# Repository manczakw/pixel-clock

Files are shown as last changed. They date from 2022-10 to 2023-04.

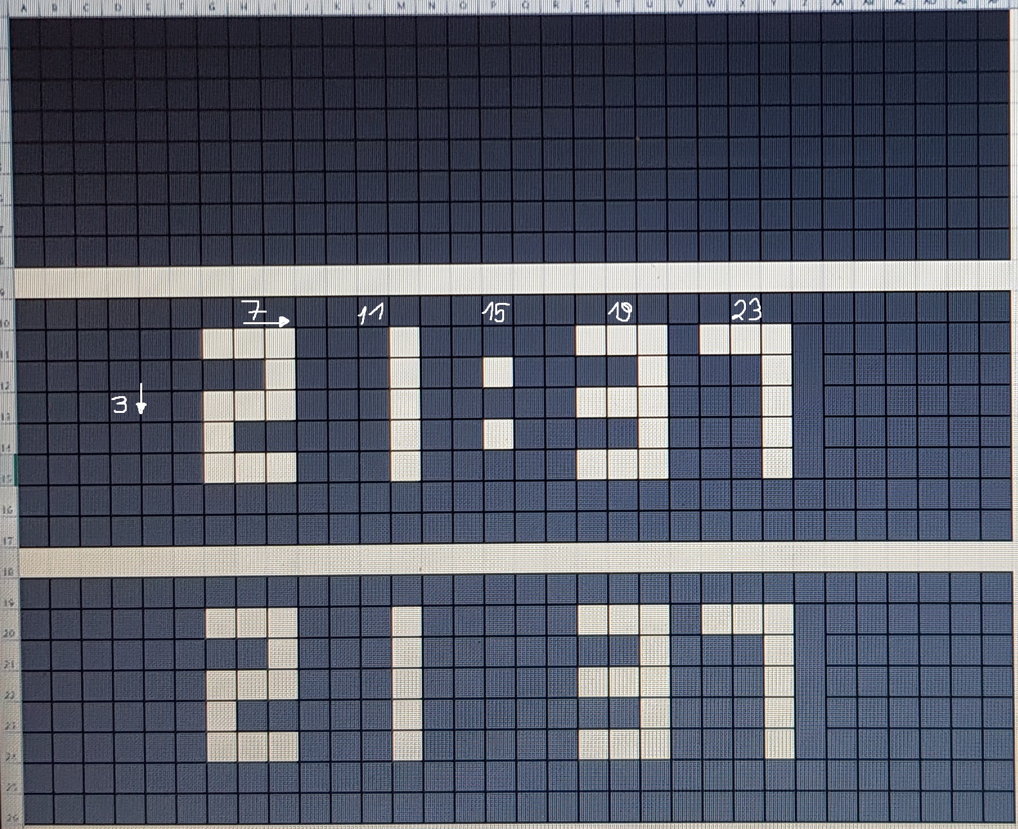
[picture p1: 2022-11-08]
Software/Time positioning.jpg

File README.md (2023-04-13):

Smart LED Pixel Clock
https://www.thingiverse.com/thing:5729760

Vievports

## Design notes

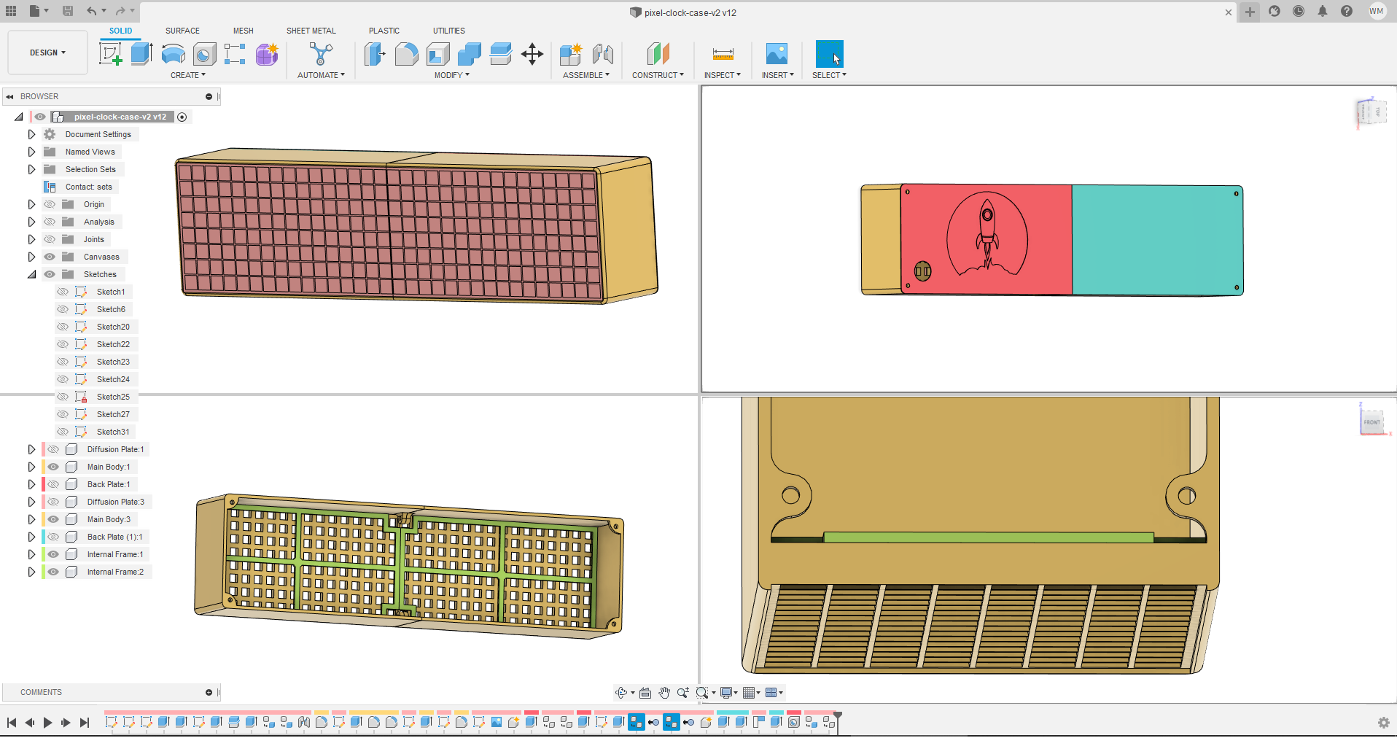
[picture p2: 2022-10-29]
Hardware/Case/CaseV2.0/Vievports.png

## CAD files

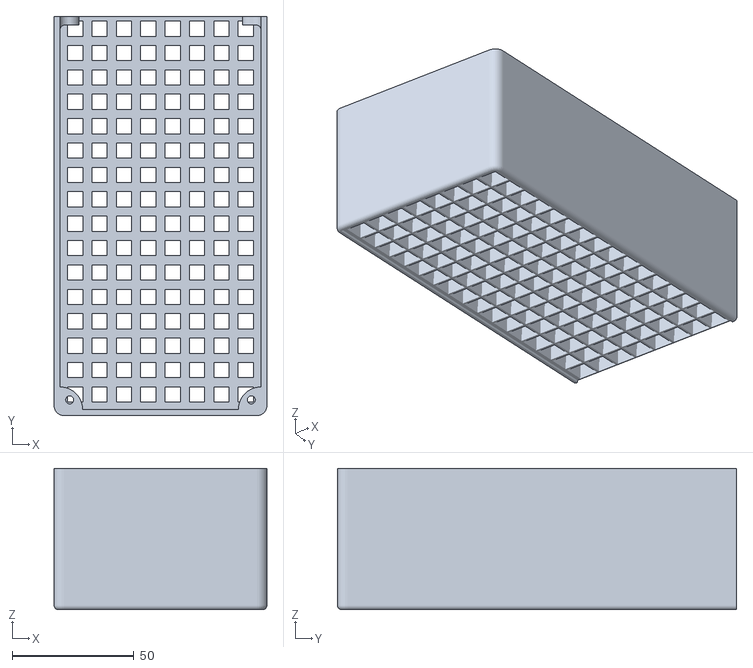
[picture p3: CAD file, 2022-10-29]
Hardware/Case/CaseV2.0/Main Body.stl
87.3 x 163.6 x 58.0

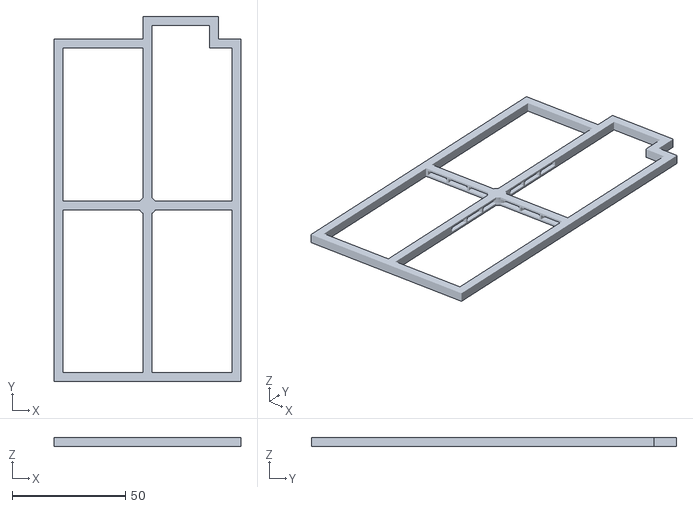
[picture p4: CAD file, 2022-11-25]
Hardware/Case/CaseV2.0/Internal Frame.stl
82.5 x 161.2 x 4.00

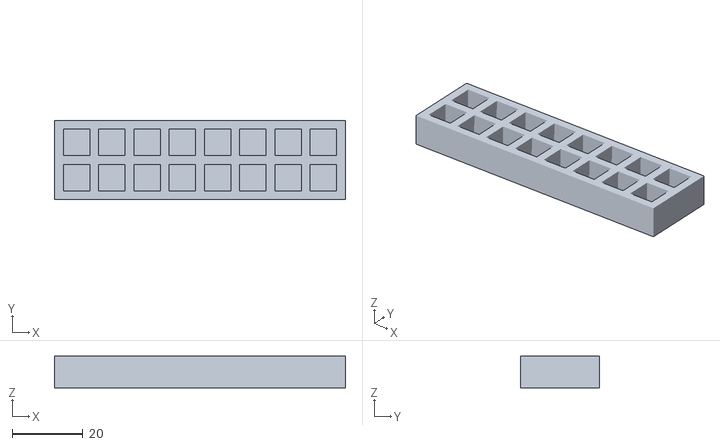
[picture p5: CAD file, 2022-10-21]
Hardware/Case/Layer Thickness test/0_12mm test 2x8.stl
82.5 x 22.5 x 9.01

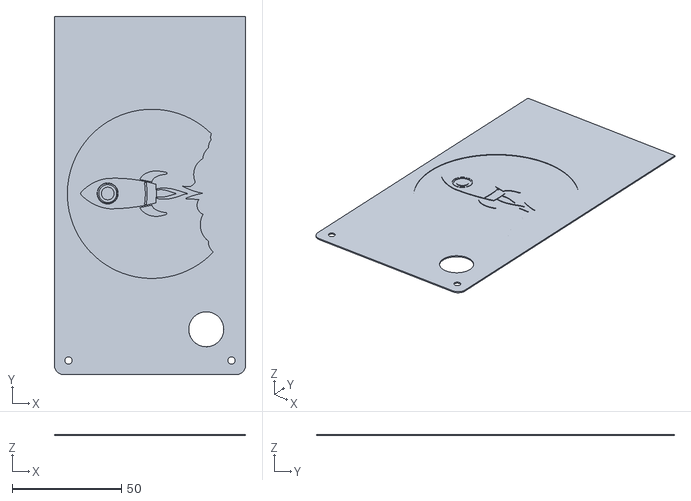
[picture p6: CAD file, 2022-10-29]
Hardware/Case/CaseV2.0/Back Plate ROCKET.stl
87.3 x 163.6 x 0.6

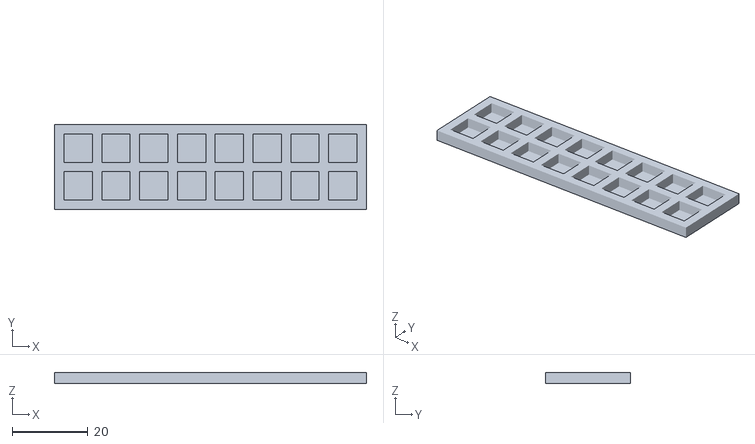
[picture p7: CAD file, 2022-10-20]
Hardware/Case/Layer Thickness test/0_2mm test 2x8.stl
82.5 x 22.5 x 2.95

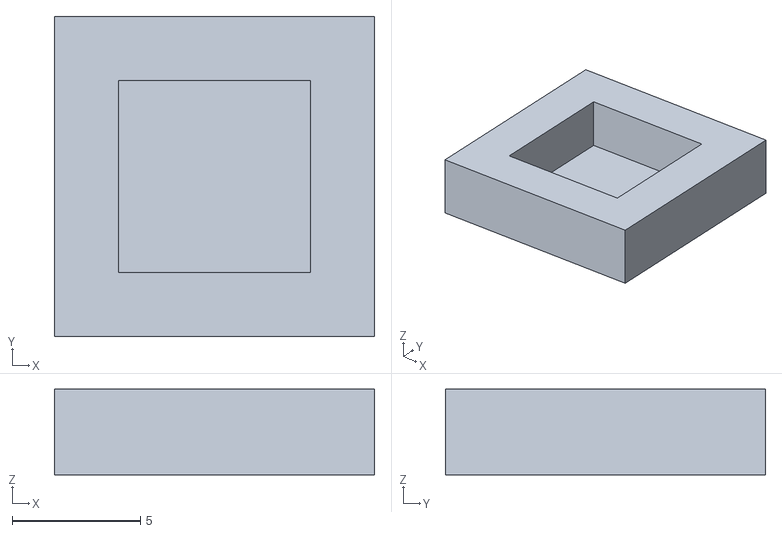
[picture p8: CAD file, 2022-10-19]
Hardware/Case/Layer Thickness test/0_6mm test.stl
12.5 x 12.5 x 3.35

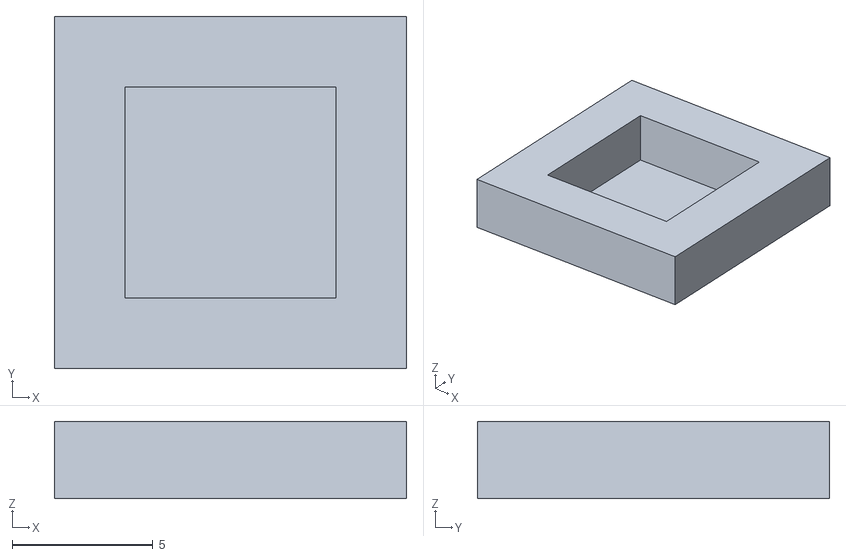
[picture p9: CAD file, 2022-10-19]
Hardware/Case/Layer Thickness test/0_2mm test.stl
12.5 x 12.5 x 2.75

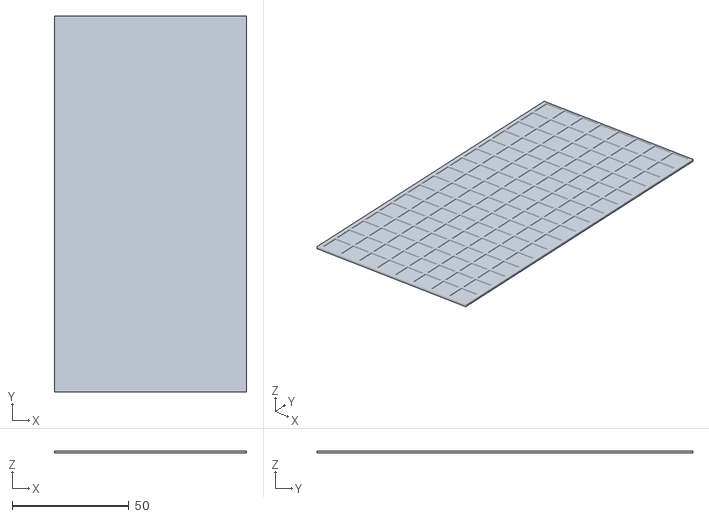
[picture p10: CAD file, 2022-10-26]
Hardware/Case/CaseV2.0/Diffusion Plate.stl
82.5 x 161.2 x 1.02

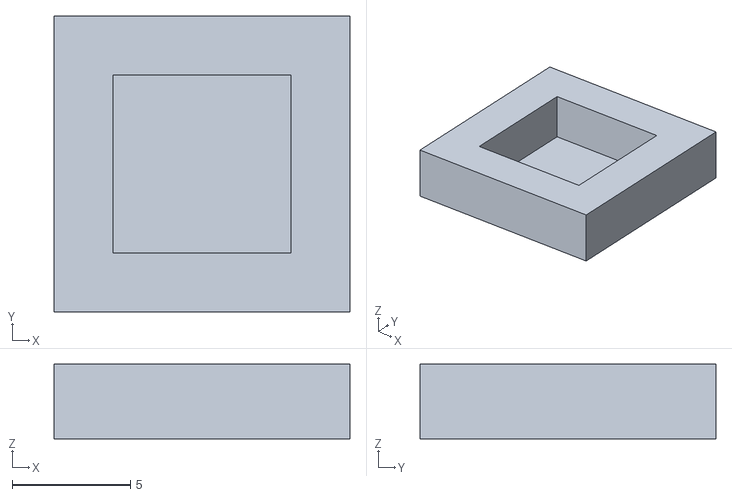
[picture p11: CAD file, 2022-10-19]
Hardware/Case/Layer Thickness test/0_4mm test.stl
12.5 x 12.5 x 3.15

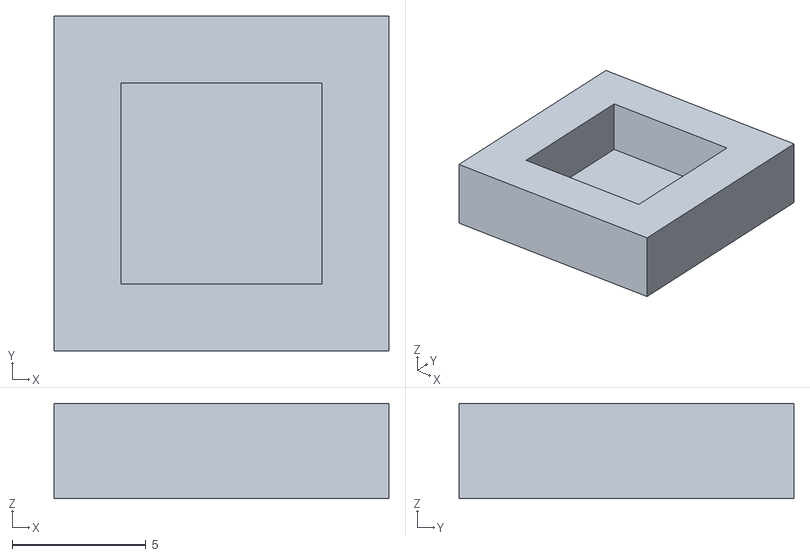
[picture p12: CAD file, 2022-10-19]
Hardware/Case/Layer Thickness test/0_8mm test.stl
12.5 x 12.5 x 3.55

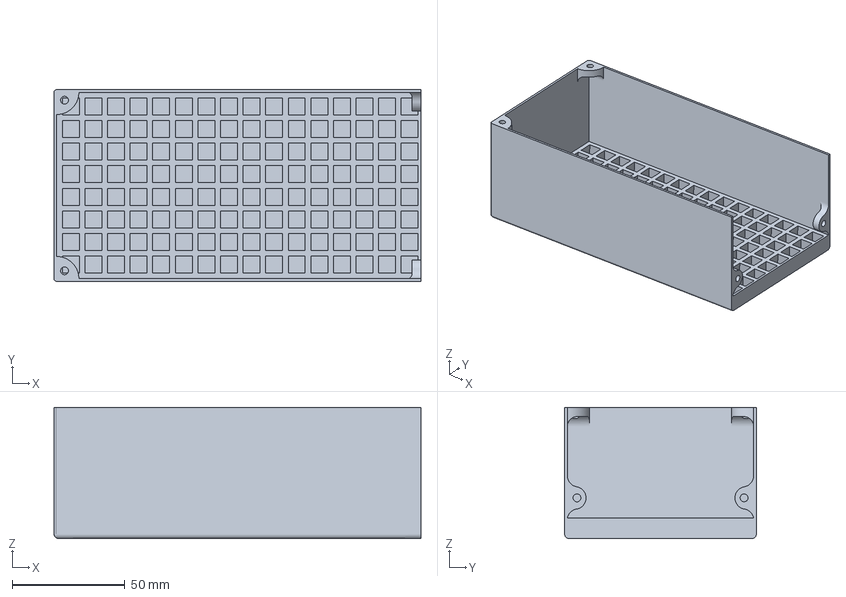
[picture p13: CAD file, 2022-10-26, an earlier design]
Hardware/Case/CaseV1.0/MainBodyP1__9h41_SQPLA.3mf
162.4 x 84.9 x 58.0 mm

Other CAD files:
Hardware/Case/CaseV2.0/Back Plate.stl
Hardware/Case/CaseV1.0/MainBodyP19h41SQPLA__9h30_SQPLA.3mf
Hardware/Case/CaseV1.0/MainBodyP1__9h20_SQPLA.3mf
Hardware/Case/CaseV1.0/Component2.stl
Hardware/Case/CaseV1.0/Component3.stl
Hardware/Case/CaseV1.0/NO-HOLES-VER/Main-body.f3d
Hardware/Case/CaseV1.0/pixel-clock-case.f3d
Hardware/Case/CaseV2.0/pixel-clock-case-v2.f3d

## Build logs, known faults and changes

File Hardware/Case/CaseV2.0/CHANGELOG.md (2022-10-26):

- Replaced transparent 0.12mm layer with separate part, in order to make printing easier (if the first layer gets mesed up, you can quickly reprint it and snap in)
- Changed angles of led's grid for better light effect.

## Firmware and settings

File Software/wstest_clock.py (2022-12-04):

from sqlite3 import Row
from turtle import delay
import board
import neopixel
import time
import random
import sys
from datetime import datetime
 
 
# returns current date and time
now = datetime.now()
print("now = ", now)

NumOfLeds = 256
NumOfRows = 8
NumOfColumns = 32

DataPin = board.D18

pixels = neopixel.NeoPixel(DataPin, NumOfLeds)

LookUpTable = [[248,247,232,231,216,215,200,199,184,183,168,167,152,151,136,135,120,119,104,103,88,87,72,71,56,55,40,39,24,23,8,7],
[249,246,233,230,217,214,201,198,185,182,169,166,153,150,137,134,121,118,105,102,89,86,73,70,57,54,41,38,25,22,9,6],
[250,245,234,229,218,213,202,197,186,181,170,165,154,149,138,133,122,117,106,101,90,85,74,69,58,53,42,37,26,21,10,5],
[251,244,235,228,219,212,203,196,187,180,171,164,155,148,139,132,123,116,107,100,91,84,75,68,59,52,43,36,27,20,11,4],
[252,243,236,227,220,211,204,195,188,179,172,163,156,147,140,131,124,115,108,99,92,83,76,67,60,51,44,35,28,19,12,3],
[253,242,237,226,221,210,205,194,189,178,173,162,157,146,141,130,125,114,109,98,93,82,77,66,61,50,45,34,29,18,13,2],
[254,241,238,225,222,209,206,193,190,177,174,161,158,145,142,129,126,113,110,97,94,81,78,65,62,49,46,33,30,17,14,1],
[255,240,239,224,223,208,207,192,191,176,175,160,159,144,143,128,127,112,111,96,95,80,79,64,63,48,47,32,31,16,15,0]]

digits =[
   #0
  [[1,1,1],
   [1,0,1],
   [1,0,1],
   [1,0,1],
   [1,1,1]],
   #1
  [[0,0,1],
   [0,0,1],
   [0,0,1],
   [0,0,1],
   [0,0,1]],
   #2
  [[1,1,1],
   [0,0,1],
   [1,1,1],
   [1,0,0],
   [1,1,1]],
   #3
  [[1,1,1],
   [0,0,1],
   [1,1,1],
   [0,0,1],
   [1,1,1]],
   #4
  [[1,0,1],
   [1,0,1],
   [1,1,1],
   [0,0,1],
   [0,0,1]],
   #5
  [[1,1,1],
   [1,0,0],
   [1,1,1],
   [0,0,1],
   [1,1,1]],
   #6
  [[1,1,1],
   [1,0,0],
   [1,1,1],
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
   #none
  [[0,0,0],
   [0,0,0],
   [0,0,0],
   [0,0,0],
   [0,0,0]]
]

digitsCenter = [
   [3,7], #hh
   [3,11], #h
   [3,19], [3,17], #mm & alternative mm 
   [3,23], [3,21] #m & alternative m
]
def setLedMatrix (row, column,value):
   pixels[LookUpTable[row][column]] = value

def setTime( hh,h,mm,m,colour):
   for vertical in range(-2,3):
      for horizontal in range(-1,2):

        if (hh == 0):
            r=0
            g=0
            b=0

        else:
            r = digits[hh][vertical+2][horizontal+1] * colour[0]
            g = digits[hh][vertical+2][horizontal+1] * colour[1]
            b = digits[hh][vertical+2][horizontal+1] * colour[2]
                     
        setLedMatrix (digitsCenter[0][0]+vertical, digitsCenter[0][1]+horizontal,(r,g,b))

        r = digits[h][vertical+2][horizontal+1] * colour[0]
        g = digits[h][vertical+2][horizontal+1] * colour[1]
        b = digits[h][vertical+2][horizontal+1] * colour[2]
              
        setLedMatrix (digitsCenter[1][0]+vertical, digitsCenter[1][1]+horizontal,(r,g,b))


        r = digits[mm][vertical+2][horizontal+1] * colour[0]
        g = digits[mm][vertical+2][horizontal+1] * colour[1]
        b = digits[mm][vertical+2][horizontal+1] * colour[2]
        
        if(mm == 1):
            setLedMatrix (digitsCenter[3][0]+vertical, digitsCenter[3][1]+horizontal,(r,g,b))
        else:
            setLedMatrix (digitsCenter[2][0]+vertical, digitsCenter[2][1]+horizontal,(r,g,b))
       
        r = digits[m][vertical+2][horizontal+1] * colour[0]
        g = digits[m][vertical+2][horizontal+1] * colour[1]
        b = digits[m][vertical+2][horizontal+1] * colour[2]

        if(mm == 1):
            setLedMatrix (digitsCenter[5][0]+vertical, digitsCenter[5][1]+horizontal,(r,g,b))
        else:
            setLedMatrix (digitsCenter[4][0]+vertical, digitsCenter[4][1]+horizontal,(r,g,b))
     
        

def updateCollon(second,colour):
   if(second%2 == 0):
      setLedMatrix(2,15,colour)
      setLedMatrix(4,15,colour)
   else:
      setLedMatrix(2,15,(0,0,0))
      setLedMatrix(4,15,(0,0,0))
 


while True:
 now = datetime.now()

 hh = now.hour//10
 h = now.hour%10
 mm = now.minute//10
 m = now.minute%10
 s = now.second
 
 
#-------------------------------------------

 if(now.hour <= 7):
   colour = (1,0,0)
 else:
   colour = (15,15,15)

 setTime(hh,h,mm,m,colour)
 updateCollon(s,colour)
 
 time.sleep(0.1)

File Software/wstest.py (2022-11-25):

from sqlite3 import Row
from turtle import delay
import board
import neopixel
import time
import random
import sys

NumOfLeds = 256
NumOfRows = 8
NumOfColumns = 32

DataPin = board.D18

pixels = neopixel.NeoPixel(DataPin, NumOfLeds)

def OneHot():
    for i in range(NumOfLeds):
           R = random.randint(0, 255)
           G = random.randint(0, 255-R)
           B = random.randint(0, 255-G-R)
           pixels[i] = (R,G,B)
           time.sleep(0.010)
           pixels[i] = (0,0,0) 

def TwoRows():
    for i in range(16):
        R = random.randint(0, 255)
        G = random.randint(0, 255-R)
        B = random.randint(0, 255-G-R)
        pixels[i] = (R,G,B)
    time.sleep(5)
    for i in range(16):
        pixels[i] = (0,0,0)
    time.sleep(5)

def FourRows():
    for i in range(256):
        R = random.randint(0, 10)
        G = random.randint(0, 10-R)
        B = random.randint(0, 10-G-R)
        pixels[i] = (R,G,B)
    time.sleep(5)
    for i in range(256):
        pixels[i] = (0,0,0)
    time.sleep(5)

def six():
    
       
        pixels[2] = (125,125,125)
        pixels[3] = (125,125,125)
        pixels[4] = (125,125,125)
        pixels[13] = (125,125,125)
        pixels[18] = (125,125,125)
        pixels[19] = (125,125,125)
        pixels[20] = (125,125,125)
        pixels[11] = (125,125,125)
        pixels[21] = (125,125,125)
        pixels[22] = (125,125,125)
        pixels[9] = (125,125,125)
        pixels[6] = (125,125,125)

def BlackDown():
    for i in range(NumOfLeds):  
        pixels[i] = (0,0,0) 

while True:
    OneHot()
    #FourRows()
    #pixels[0] = (255,255,255)
    #pixels[12] = (255,255,255)
    #six()








            
          
       
    
   

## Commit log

2022-10-19 Initial commint, added cubes to test which front thickness looks best
    [0_2mm test.stl, 0_4mm test.stl, 0_6mm test.stl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]
2022-10-20 Added quick test to check all diodes
2022-10-20 Added KiCad schematic Added new test to wstest Added 2x8 0.2mm case test
    [0_2mm test 2x8.stl, pixel-clock.kicad_pcb, pixel-clock.kicad_sch]
2022-10-21 Added print test for 0.12mm layer
    [0_12mm test 2x8.stl]
2022-10-21 Created V1.0 Case/Main Body
    [Main-body.f3d, MainBodyP1.stl, MainBodyP2.stl]
2022-10-22 Updated fusion 360 file to match existing stl's
    [Main-body.f3d]
2022-10-22 Added screw holes to join two halfs together
    [Main-body.f3d, MainBodyP1.stl, MainBodyP2.stl]
2022-10-22 Remove holes from the both sides
    [Main-body.f3d, MainBodyP1.stl, MainBodyP2.stl]
2022-10-22 Fixed inner screw holes
    [Main-body.f3d, MainBodyP1.stl, MainBodyP2.stl]
2022-10-23 Rounded conector between hafs & added mouting points for backplate
    [Main-body.f3d, MainBodyP1.stl, MainBodyP1__9h20_SQPLA.3mf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]
2022-10-23 Update README.md
    No holes version + screws
2022-10-23 Moved to separate folder
    [Main-body.f3d, MainBodyP1.stl, MainBodyP2.stl]
2022-10-23 File clean up
    [Component2.stl, Component3.stl, pixel-clock-case.f3d]
2022-10-26 Added V2 files
    [Back Plate.stl, Diffusion Plate.stl, Main Body.stl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]
2022-10-29 Added internal frame to better hold the led matrix
    [Back Plate ROCKET.stl, Back Plate.stl, Internal Frame.stl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]
2022-11-08 Added circuit preview
2022-11-25 Internal frame improvments, code cleanup, nightmode
    [Internal Frame.stl]
